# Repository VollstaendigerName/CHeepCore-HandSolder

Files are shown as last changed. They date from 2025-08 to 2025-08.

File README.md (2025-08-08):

# CHeepCore-HandSolder
CHeepCore in a variant with larger footprints and TSSOP package for easier hand soldering.
A minimalist, ultra-low-cost RISC-V development board based on the CH32V003 series. Designed for embedded hobbyists, students, and low-cost prototyping.

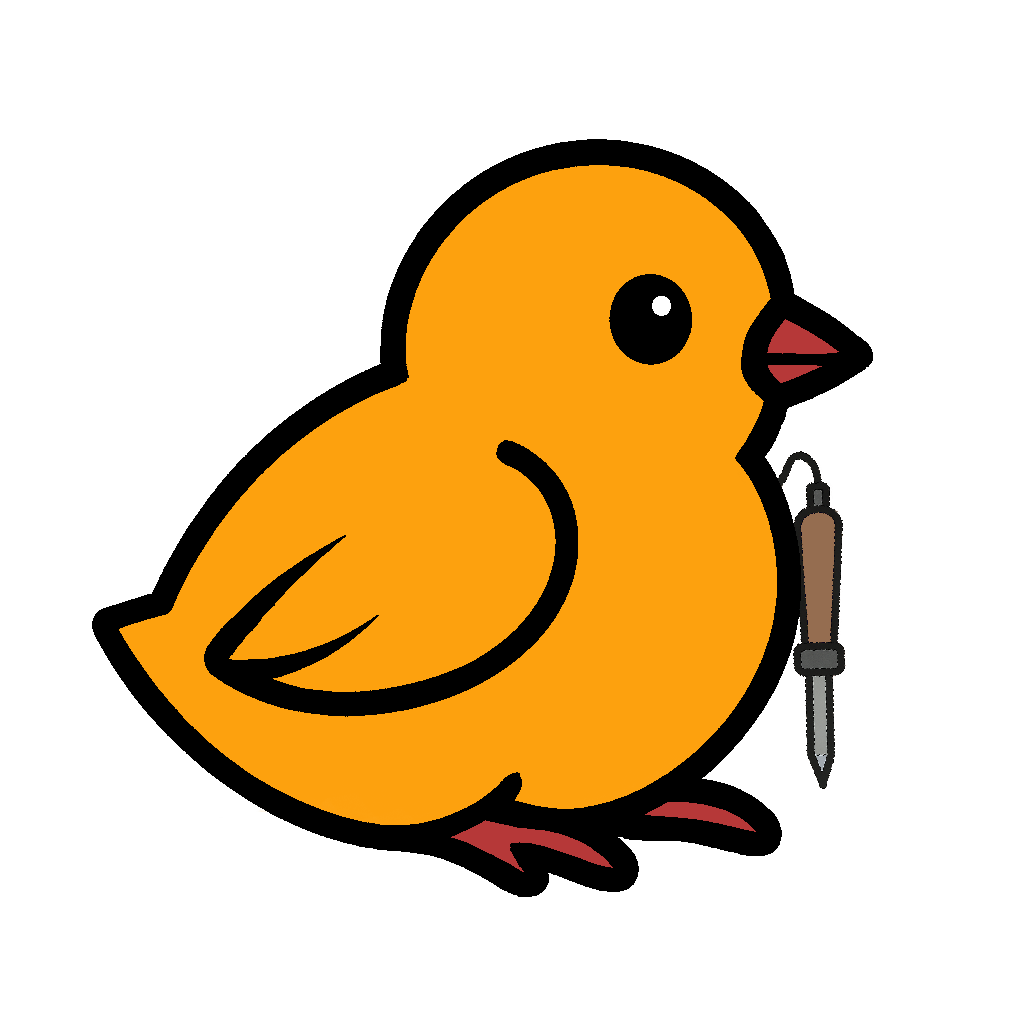
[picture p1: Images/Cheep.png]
CHeepCore Logo


---

## Project Information

- **Name:** CHeepCore-HandSolder  
- **Revision:** 0.0.1b  
- **Date:** 2025-08-06  
- **KiCad Version:** 9.0.3  
- **Target Audience:** Embedded hobbyists, students, low-cost prototyping  
- **Cost Goal:** Complete microcontroller board for under 0.50€  

---

## Key Features

- CH32V003F4U6 32-bit RISC-V microcontroller (20-pin QFN)  
- 16 GPIOs exposed on 2.54 mm headers (PC0–PC7, PD0–PD7)  
- External 24 MHz crystal with 22 pF load capacitors  
- USB-C power input (VBUS → 3.3 V LDO)  
- Configurable solder jumpers for:  
  - USB-VBUS disconnect  
  - 3.3 V / 5 V MCU supply  
- SWD/JTAG programming connectors (3-pin & 10-pin, WCH-LinkE compatible)  
- Breadboard-compatible PCB outline (18.288 × 32.004 mm)  

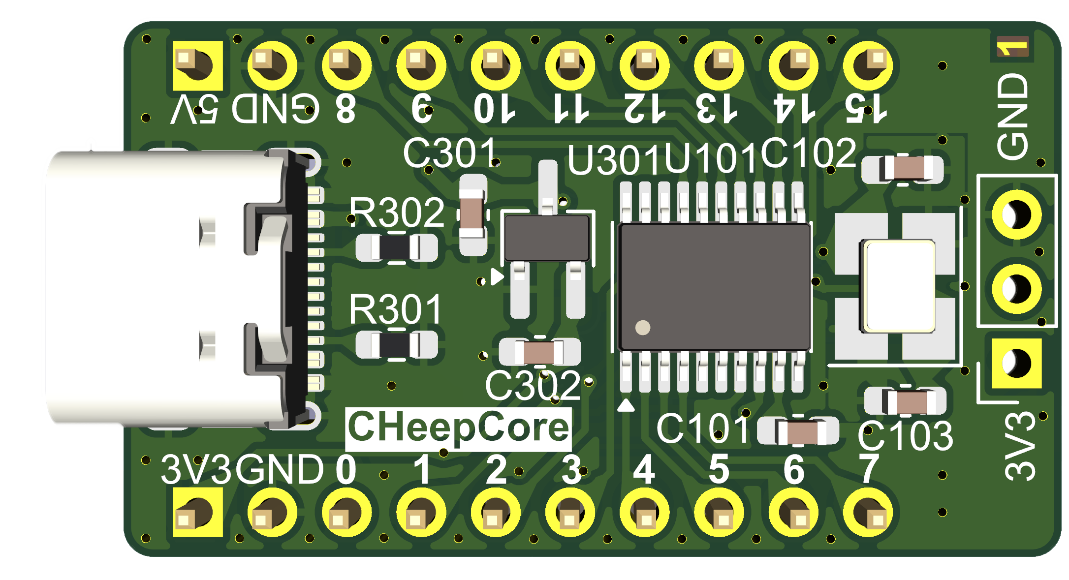
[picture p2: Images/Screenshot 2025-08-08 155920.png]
CHeepCore front


---

## Power Configuration

1. **USB-C Supply**  
   VBUS (5 V) feeds on-board LDO → 3.3 V rail  

2. **External Supply**  
   - Cut the USB-disconnect jumper (bottom side) to isolate VBUS  
   - Inject external 5 V or 3.3 V via header  

3. **MCU Voltage Selection**  
   - Default: 3.3 V  
   - For 5 V operation, cut the 3.3 V jumper (bottom side) and bridge the center pad to 5 V  

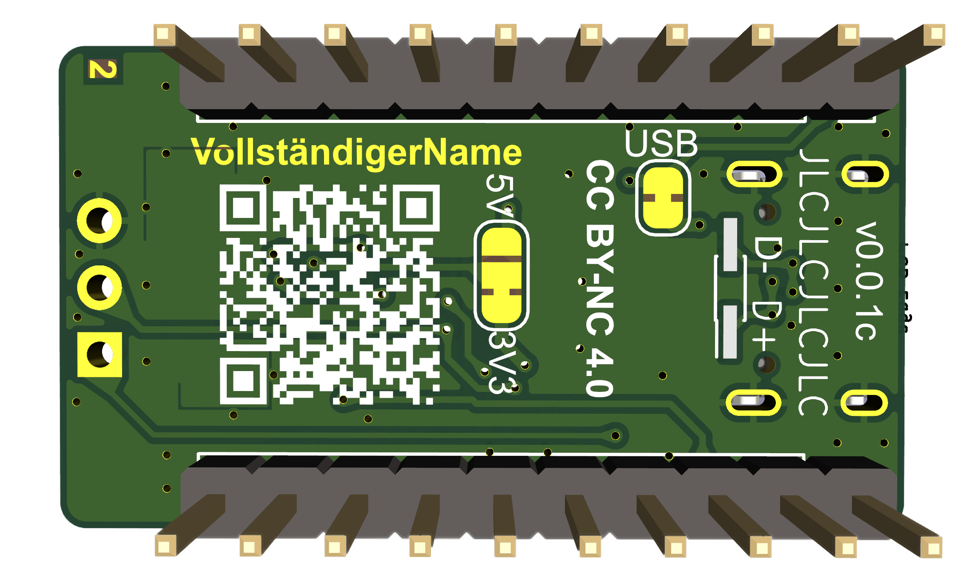
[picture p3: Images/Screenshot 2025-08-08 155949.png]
CHeepCore back


---

## Programming with WCH-LinkE

- Connect **3V3** and **GND** pins  
- Connect **SWDIO/TMS** to the middle pin of the 3-pin header  
- SWCLK/TCK and reset lines available on 10-pin header for full JTAG  

---

## Mechanical Dimensions

- **Width:** 32.004 mm  
- **Height:** 18.288 mm  
- Compatible with standard 2.54 mm breadboards  

---

## GPIO Pinout

| # | Header Pin | Default Function | Alternate Function |
| --- | --- | --- | --- |
| 0 | PD0 | T1CH1N / OPN1 | SDA / UTX |
| 1 | PD1 | SWIO / AETR2 | T1CH3N / SCL / URX |
| 2 | PD2 | A3 / T1CH1 / T2CH3 | T1CH2N |
| 3 | PD3 | A4 / T2CH2 / AETR | UCTS / T1CH4 |
| 4 | PD4 | A7 / UCK / T2CH1ETR | OPO / T1CH4ETR |
| 5 | PD5 | A5 / UTX | T2CH4 / URX |
| 6 | PD6 | A6 / URX | T2CH3 / UTX |
| 7 | PD7 | NRST / T2CH4 | OPP1 / UCK |
| 8 | PC7 | MISO / T1CH2 | T2CH2 / URTS |
| 9 | PC6 | MOSI / T1CH1CH3N | UCTS / SDA |
| 10  | PC5 | SCK / T1ETR / T2CH1ETR | SCL / UCK / T1CH3 |
| 11  | PC4 | A2 / T1CH4 / MCO | T1CH1CH2N |
| 12  | PC3 | T1CH3 / T1CHIN | UCTS |
| 13  | PC2 | SCL / URTS / T1BKIN | AETR / T2CH2 / T1ETR |
| 14  | PC1 | SDA / NSS / T2CH4 | T2CH1ETR / T1BKIN / URX |
| 15  | PC0 | T2CH3 / UTX | NSS / T1CH3 |

---
## Bill of Material (BoM)

| Reference | Qty | Unit Price (€) | Description |
|---|:---:|---:|---|
| C101 |  1  | 0.0020  | YAGEO CC0603KRX7R7BB104 (100 nF, 0603) |
| C102, C103 |  2  | 0.0016  | YAGEO CC0603JRNPO9BN220 (22 pF, 0603) |
| C301, C302 |  2  | 0.0033  | Samsung CL10A105KB8NNNC (1 µF, 0603) |
| J301 |  1  | 0.0300  | SHOU HAN TYPE-C 16-PIN 2MD(073) |
| R301, R302 |  2  | 0.0004  | VO SCR0603J5K1 (5.1 kΩ, 0603) |
| U101 |  1  | 0.1349  | CH32V003F4P6 (32-bit RISC-V microcontroller) |
| U301 |  1  | 0.0047  | Megain MG6206K3B-33 (3.3 V LDO) |
| Y101 |  1  | 0.0323  | TOGNJING XTM32024000DT00351001 (24 MHz crystal) |

---

## Author & License

   VollständigerName  GitHub: https://github.com/VollstaendigerName

   <small><span style="color:lightgrey;">
   This work is licensed under Creative Commons Attribution-NonCommercial 4.0 International (CC BY-NC 4.0). See LICENSE.txt for details.

   This hardware specification and documentation have been prepared to the best of the author’s knowledge, but are provided without any warranty. The author accepts no liability for malfunctions, consequential damages, or any claims arising from the use of this information, the design, or the implemented hardware. Any liability is expressly excluded.
   </span></small>

## Repository Contents

```text
/
├── CHeepCore/       # KiCad schematic and PCB files
├── Images/          # Images of the 3d Model
├── production/      # Gerber export for fabrication   
├── README.md        # This file  
└── LICENSE.txt      # CC BY-NC 4.0

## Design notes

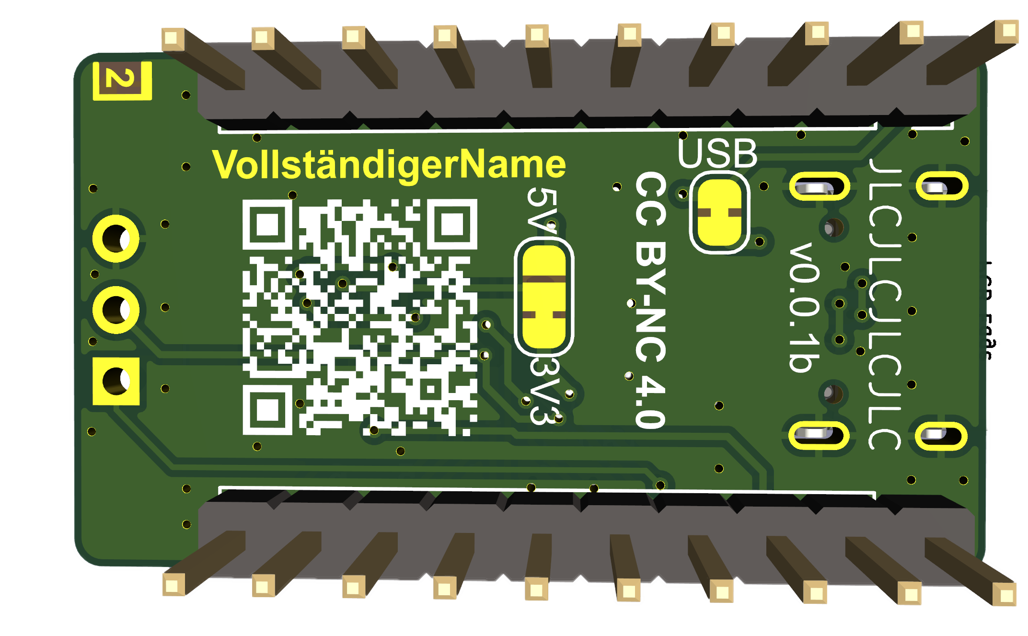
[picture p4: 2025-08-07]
Images/Screenshot 2025-08-07 172043.png

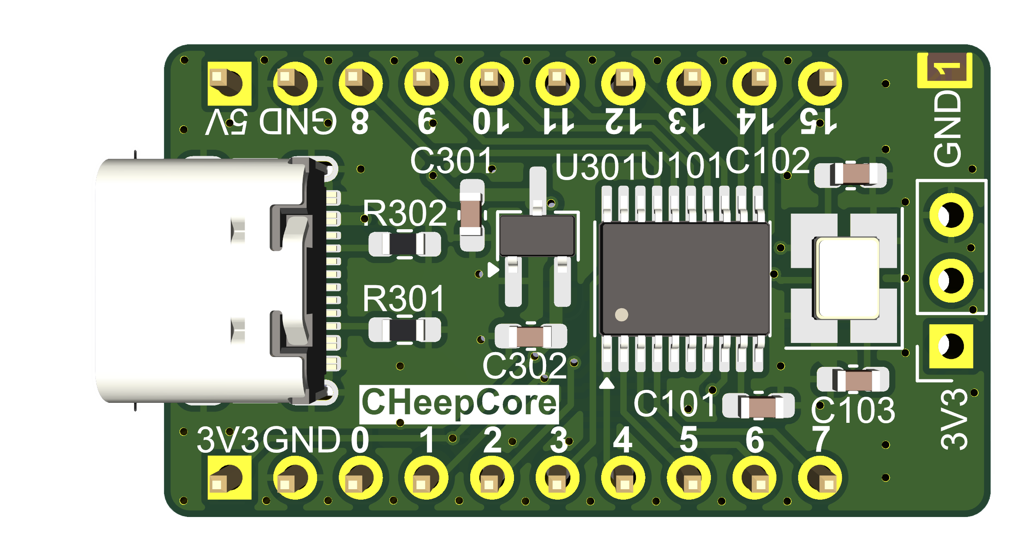
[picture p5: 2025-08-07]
Images/Screenshot 2025-08-07 172010.png

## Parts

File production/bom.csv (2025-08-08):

Designator | Footprint | Quantity | Value | LCSC Part #
C101 | 0603 | 1 | 100nF | https://www.lcsc.com/product-detail/C108079.html?s_z=n_CC0603KRX7R7BB104
C102, C103 | 0603 | 2 | 22pF | https://www.lcsc.com/product-detail/C105620.html
C301, C302 | 0603 | 2 | 1µF | https://www.lcsc.com/product-detail/C15849.html
J101, J102 | PinSocket_1x10_P2.54mm_Vertical | 2 | Conn_01x10
J103 | PinHeader_2x01_P1.00mm_Vertical_SMD | 1 | USB
J201 | PinSocket_1x03_P2.54mm_Vertical | 1 | Conn_01x03
J301 | USB_C_Receptacle_GCT_USB4105-xx-A_16P_TopMnt_Horizontal | 1 | USB_C_Receptacle_USB2.0_16P | https://www.lcsc.com/product-detail/C2765186.html?s_z=n_USB%2520C
R301, R302 | 0603 | 2 | 5k1 | https://www.lcsc.com/product-detail/C3017721.html
U101 | TSSOP-20_4.4x6.5mm_P0.65mm | 1 | CH32V003FxPx | https://www.lcsc.com/product-detail/C5187096.html
U301 | TSOT-23_HandSoldering | 1 | 3V3 LDO | https://www.lcsc.com/product-detail/C48678136.html
Y101 | Crystal_SMD_3225-4Pin_3.2x2.5mm_HandSoldering | 1 | Crystal_GND24 | https://www.lcsc.com/product-detail/C41383243.html?s_z=n_24Mhz

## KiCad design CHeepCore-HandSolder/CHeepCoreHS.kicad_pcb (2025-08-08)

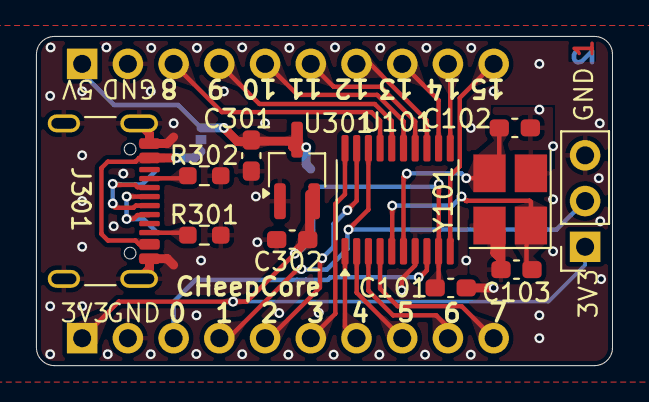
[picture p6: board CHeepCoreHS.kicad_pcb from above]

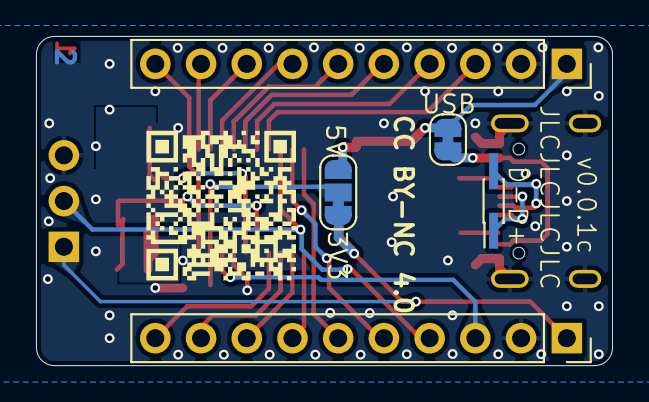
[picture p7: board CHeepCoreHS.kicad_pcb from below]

Board: 2 copper layers, 32.0 x 18.3 mm, 17 parts (5 on the bottom side), 27 nets.

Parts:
C101: 100nF; C_0603_1608Metric_Pad1.08x0.95mm_HandSolder
C102, C103: 22pF; C_0603_1608Metric_Pad1.08x0.95mm_HandSolder
C301, C302: 1µF; C_0603_1608Metric_Pad1.08x0.95mm_HandSolder
J101, J102: Conn_01x10; PinSocket_1x10_P2.54mm_Vertical
J103: USB; PinHeader_2x01_P1.00mm_Vertical_SMD
J201: Conn_01x03; PinSocket_1x03_P2.54mm_Vertical
J301: USB_C_Receptacle_USB2.0_16P; USB_C_Receptacle_GCT_USB4105-xx-A_16P_TopMnt_Horizontal
JP101: 3V3 or 5V; SolderJumper-3_P1.3mm_Bridged12_RoundedPad1.0x1.5mm_NumberL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
JP301: USB Disconnect; SolderJumper-2_P1.3mm_Bridged_RoundedPad1.0x1.5mm
R301, R302: 5k1; R_0603_1608Metric_Pad0.98x0.95mm_HandSolder
U101: CH32V003FxPx; TSSOP-20_4.4x6.5mm_P0.65mm
U301: 3V3 LDO; TSOT-23_HandSoldering
Y101: Crystal_GND24; Crystal_SMD_3225-4Pin_3.2x2.5mm_HandSoldering

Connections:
+3V3: C302.1, J102.1, J201.1, JP101.1 (A), U301.2 (VO)
+5V: C301.1, J101.1, JP101.3 (B), JP301.2 (B), U301.3 (VI)
/PC0: J101.10, U101.10 (PC0)
/PC1: J101.9, U101.11 (PC1)
/PC2: J101.8, U101.12 (PC2)
/PC3: J101.7, U101.13 (PC3)
/PC4: J101.6, U101.14 (PC4)
/PC5: J101.5, U101.15 (PC5)
/PC6: J101.4, U101.16 (PC6)
/PC7: J101.3, U101.17 (PC7)
/PD0: J102.3, U101.8 (PD0)
/PD1: J102.4, J201.2, U101.18 (PD1)
/PD2: J102.5, U101.19 (PD2)
/PD3: J102.6, U101.20 (PD3)
/PD4: J102.7, U101.1 (PD4)
/PD5: J102.8, U101.2 (PD5)
/PD6: J102.9, U101.3 (PD6)
/PD7: J102.10, U101.4 (PD7)
/USB with LDO/D+: J103.1, J301.A6 (D+), J301.B6 (D+)
/USB with LDO/D-: J103.2, J301.A7 (D-), J301.B7 (D-)
GND: C101.2, C102.2, C103.2, C301.2, C302.2, J101.2, J102.2, J201.3, J301.A1 (GND), J301.A12 (GND), J301.B1 (GND), J301.B12 (GND), J301.S1 (SHIELD), R301.2, R302.2, U101.7 (VSS), U301.1 (GND), Y101.2, Y101.4
unnamed: J301.A5 (CC1), R302.1
unnamed: J301.B5 (CC2), R301.1
unnamed: C101.1, JP101.2 (C), U101.9 (VDD)
unnamed: J301.A4 (VBUS), J301.A9 (VBUS), J301.B4 (VBUS), J301.B9 (VBUS), JP301.1 (A)
unnamed: C103.1, U101.5 (PA1), Y101.1
unnamed: C102.1, U101.6 (PA2), Y101.3

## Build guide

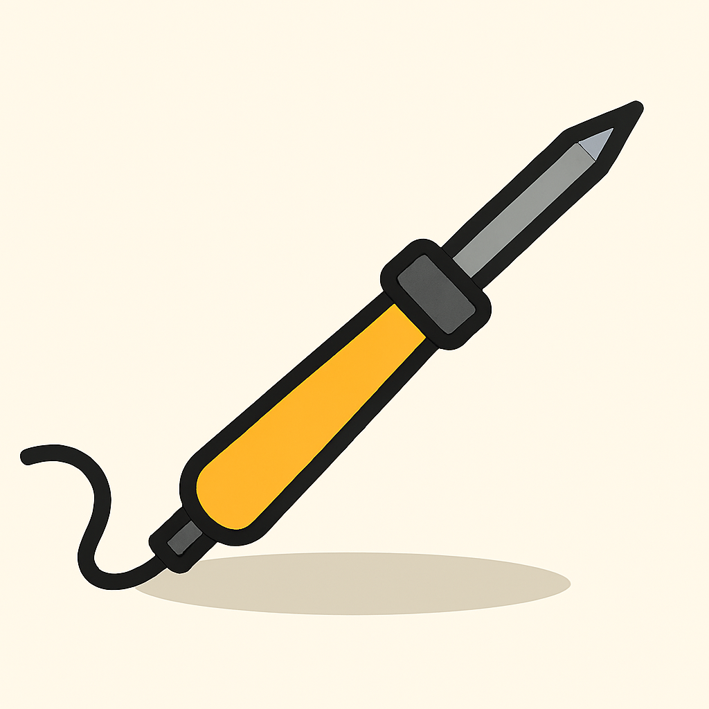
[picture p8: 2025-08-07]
CHeepCore-HandSolder/Pic/SolderingIron.png

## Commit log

2025-08-07 Upload Project
    First Upload
    [CHeepCoreHS.kicad_pcb, CHeepCoreHS.kicad_sch, Schematic.kicad_sch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]
2025-08-07 Added teardrops
    Added teardrops for better stability
    [CHeepCoreHS.kicad_pcb]
2025-08-08 Add USB smd pads on the back
    [CHeepCoreHS.kicad_pcb, CHeepCoreHS.kicad_sch, USB-C_LDO.kicad_sch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]

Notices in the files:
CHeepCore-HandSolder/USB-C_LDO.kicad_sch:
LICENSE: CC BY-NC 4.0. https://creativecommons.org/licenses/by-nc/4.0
